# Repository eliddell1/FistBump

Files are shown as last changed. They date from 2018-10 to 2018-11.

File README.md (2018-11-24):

# FistBump
[](https://github.com/eliddell1/FistBump/releases)

[](https://github.com/eliddell1/Project-Blue-Fist)

_This Repo was a P.O.C. and is deprecated for a BLE peripheral Edition. STAY TUNED!_

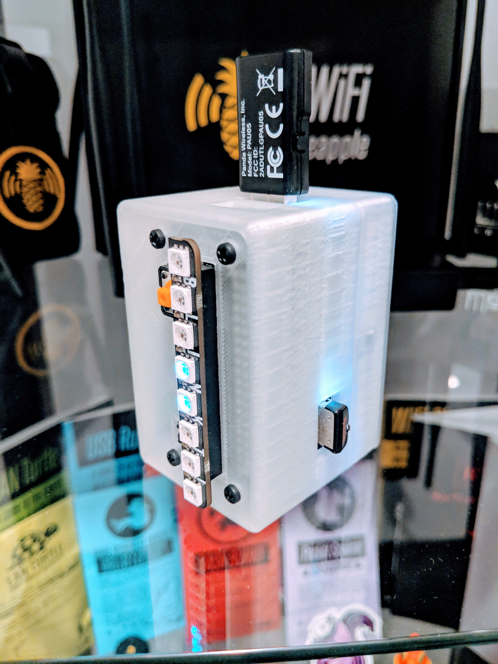
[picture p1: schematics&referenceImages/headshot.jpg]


## Introduction
When performing a typical deauth/wpa 4way handshake attack, one must get close enough to the target/clients for the deauth and capture to be effective. This can prove difficult in a typcial engagement, as one would draw suspicion setting up a laptop with a big wifi adapter sticking out and a bunch of terminal windows open.  It just screams hacker right? 

But what if you had a portable device that could launch such an attack with the click of a single button, while being small enough to be comfortably hidden in your hacker hoody pocket. A device with a low profile wifi adapter and removable storage where the handshakes are automatically stored so that you can easily transfer them to your hashcat rig when you get home. FistBump is a prototype of such a device. Did I mention it charges with a standard mini usb charger? Well it does.

__UPDATES__

As of __Version 2.0__ it will now also capture PMKID hashes as well. I migrated from aircrack to hcxdumptool.  I have left the old
fistbump.sh which utilizes the aircrack method in the repository incase for some reason someone wants that, but now the attack script is wpa_hashgrab.sh. _(It not only adds the capability to capture the PMKID hashes as well as 4 way handhsakes but its also much faster and a cleaner execution overall)_

As of __Version 2.1__ you can now target specific networks by saving a file named targets.txt to the removable USB drive with the BSSID(s) of your target(s) minus the colons. For instance, if your target BSSID is XX:XX:XX:XX:XX:XX, your targets.txt file will say XXXXXXXXXXXX. For multiple targets just put each BSSID on a new line.  HcxDumptool supports up to 64 specific targets. To revert back to a broad untargeted attack, simply remove the targets.txt file from your removable storage.

As of __version 2.2__ For every .2500 file created a .catalog file is also created of the same name.  This file is a catalog BSSIDs & ESSIDs of which handhsakes were captured. 

As of __version 2.3__ Removed all aircrack dependencies and killed wpa_supplicant instead of using `aircrack-ng check kill`

__Planned for Next Release__
* support potential capturing of plainmasterkeys, usernames and password

## Using FistBump

To power on FistBump, hold down the small button for about a second or until the red light on the bottom of the device goes off.  When the device is ready it will show either a __single green light__ or a __blue pulsing pattern__ on the strip of leds at the top of the device. Both indicate that the device is armed and ready to attack. The __single green light__ simply means there are currently no hashes stored on the device, while the __blue pulsing pattern__ indicates how many hash files are currently saved on the device. 

_Note: (pulse, pulse, pause, repeat) would mean 2 hash files are saved. Hash files can contain more than one hash and from more than one network. The hash files are saved to the external usb drive with the naming convention {date_time_Captured}.{hashcat mode}. For example, 4 way handshakes are cracked using `$ hashcat -m 2500... `, so a file containing 4 way handshakes would be named 201810290107.2500 while a PMKID hash file captured from the same attack would be 201810290107.16800, as the hashcat mode forcracking PMKID is 16800._  As of Version 2.1 if you specified a target (see updates section for v2.2), the captured hashes will be prepended with "targeted_" example: targted_201810290107.2500

### Starting an Attack 

To start an attack simply press the larger button.   

Before the actual attack begins, FistBump will make sure you have a USB thumb drive attached, where it will store the hashes it collects.  If no USB drive is present. it will light the strip up __solid red__ to indicate the missing drive and abort, sending you back to the ready state mentioned above.  Don't worry, you can simply insert your USB thumbdrive and try again. 

With a thumb drive present it will begin by putting your wifi adapter into the proper state, monitor mode, and kill any processes, like wpa_supplicant, that may interfere.  This stage will be indicated by a __purple scan pattern__. 

When you see a __random flashing rainbow pattern__ or __random flashing purple pattern__, the attack has begun! 
The Rainbow pattern indicates you are doing a broad attack while the purple pattern indicates that you have specified a target (see updates section for v2.1)

The attack leverages the latest WPA/WPA2 attack tool, [hcxdumptool](https://hashcat.net/forum/thread-7717.html) and is set to run for 40 seconds, which in my experience should be plenty of time to at least grab some handshakes.  If you wish to change this, you can edit the wpa_hashgrab.sh script found in scripts/FistBump/hashgrab.sh of this repository or in /home/pi/FistBump/ on the actual pi.

When the attack is complete you will see the strip of LEDs light up __solid purple__ if new hashes were collected during the attack, or __solid yellow__ if no new hashes were collected.

Now one might say, _"If I'm trying to be stealthy, whats with all these beautiful flashy LEDs?"_  Thats a valid point.  Again,
this is merely a proof of concept, but should you really have the need, the LED strip can be easily removed and replaced with out any altercations to the code. Of course then you just have to assume your attack went through and completed as you will have no indication.

### Powering Down

To power off FistBump, simply press the small power button again. The device will flash __solid yellow__ indicating a shutdown has begun.  Once all lights, external and internal are off, the device is off. The device will also begin a shutdown on its own when the battery gets dangerously low. This will also be indicated by the __solid yellow__ indicator and may come unexpectedly. Don't be alarmed as it is for the safety and integrety of the device img.

## Disclaimer

_This Device was developped as a proof of concept and for White Hat Purposes.  You should only use this device on your own or a consenting network and in a controlled enviroment, as sending the necessary deauth packets used in the contained scripts could be illegal in your given part of the world. I do not endorse or warrent breaking the law or invading the privacy of others. You alone are fully responsible for what you do with this info/device, and how you use it. I am not responsible for your actions. Please do not hack Wifi points that you are not allowed to!!!
Don't be a jerk!_

## What is here?
This repository contains all the Schematics, Reference Photos, Boot images, scripts, and even 3d printable encloser parts for creating a FistBump prototype device.

## Parts List

* [1 pi zero v1.3](https://www.raspberrypi.org/products/raspberry-pi-zero/)
_Do **NOT** use the wifi model as the chip doesn't support monitor/package injection and creates interferience on usb hub_

* [1 zero4u usb hub adapter](https://www.adafruit.com/product/3298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)

* [1 MakerSpot RPi Raspberry Pi Zero W Protoboard Breadboard](https://www.amazon.com/MakerSpot-Raspberry-Protoboard-Breadboard-Prototyping/dp/B01J9ILH7S)

* [2 10k resistors](https://www.amazon.com/Projects-25EP51410K0-10K-Resistors-Pack/dp/B01F06T56I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)

* [1 100k resistor](https://www.amazon.com/Projects-25EP514100K-100k-Resistors-Pack/dp/B0185FCGEY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)

* [3 1N4007 diodes]( https://www.amazon.com/100-Pieces-1N4007-Rectifier-Electronic/dp/B079KBFKK5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)

* 1 [small momentary button for power button](https://www.amazon.com/GZFY-6x6x4-5mm-Momentary-Tactile-Button/dp/B01N6GU7TA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)

* 1 [regular momentary button for Attack Trigger](https://www.amazon.com/Cylewet-12x12x7-3mm-Momentary-Tactile-Arduino/dp/B01NCQVGLC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)

* 1 [2.5 pi nylon screw set](https://www.adafruit.com/product/3299)

* 1 usb wifi adapter capable of monitor mode/ packet injection. I'd recommend the [Panda 300Mbps Wireless N USB Adapter](https://www.amazon.com/gp/product/B00EQT0YK2/ref=oh_aui_detailpage_o01_s00?ie=UTF8&psc=1) or even the [canaKit Wifi adapter](https://www.amazon.com/gp/product/B00GFAN498/ref=oh_aui_detailpage_o00_s01?ie=UTF8&psc=1) _both are capable of packet injection and fairly small YAY!_ or you could also use [this guy if you want and even smaller profile but its not as strong]( https://www.amazon.com/gp/product/B019XUDHFC/ref=oh_aui_detailpage_o00_s00?ie=UTF8&psc=1) 
For a more complete list of recommended devices [click here](https://null-byte.wonderhowto.com/how-to/buy-best-wireless-network-adapter-for-wi-fi-hacking-2018-0178550/)

* 1 [lo profile sandisk flash storage for saving handshakes in a removable manner](https://www.amazon.com/SanDisk-Cruzer-Low-Profile-Drive-SDCZ33-008G-B35/dp/B005FYNSUA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)

* 1 [16-32gb class 10 mirco sd card for pi boot image](https://www.amazon.com/s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)

* 1 [Pwerboost 1000c or 500c](https://www.adafruit.com/product/2465)

* 1 [3.7V 1200mAh PKCELL LP503562](https://www.amazon.com/s?k=3.7V+1200mAh+PKCELL+LP503562&ref=nb_sb_noss) _size matters we want a low profile as we will have a tight fit but feel free to alter this as you see fit espcially if you deisgn your own enclosuer etc_

* 1 [Pimoroni Blinkt!](https://shop.pimoroni.com/products/blinkt) _this will be your status indicator_

## Physical Assembly
For instructions on the physical assmebly follow the README file, [here](https://github.com/eliddell1/FistBump/blob/master/schematics%26referenceImages/README.md).  

I have also supplied freecad/stl files for the 3d printable encloser [here](https://github.com/eliddell1/FistBump/tree/master/EncloserFreeCad).

## Software Dependencies
This repository will supply a disk image built off [Raspbian STRETCH OS](https://github.com/eliddell1/FistBump/releases) in the releases section, that you can just write to a micro sd, pop into your piZero and be good to go! __username:pi password: fistbump__ That said, should you choose to build this yourself off of another OS or with modifications, be aware of the following dependencies.  The scripts for powering on and off the device as well as the attack button and actual attack have been suplied in the [scripts folder](https://github.com/eliddell1/FistBump/tree/master/scripts)

I chose to start the "arm_trigger" python script @reboot in crontab and the lipopi python script (for powering on and off the device) is set to start via /etc/rc.local

### version 1 dependencies

* aircrack-ng
`sudo apt install aircrack-ng`

* cowpatty
`wget http://www.willhackforsushi.com/code/cowpatty/4.6/cowpatty-4.6.tgz
tar zxfv cowpatty-4.6.tgz
cd cowpatty-4.6
make cowpatty
sudo cp cowpatty /usr/bin`

### version 2 dependencies 
* [hcxdumptool v4.2.0 or higher](https://github.com/ZerBea/hcxdumptool)

* [hcxtools v4.2.0 or higher](https://github.com/ZerBea/hcxtools)

### indicator depenencies
* blinkt! python library
`curl https://get.pimoroni.com/blinkt | bash`

## Credits
Credit where credit is due: 

* [ZerBera](https://github.com/ZerBea) for their development of hcxdumtool and hcxtools used in this prototype

* The powering on/off schematic and script were designed by [NeonHorizon](https://github.com/NeonHorizon/lipopi/blob/master/README.power_up_power_down.md)  

* Call out to 'atom' of the hashcat forums for this post: https://hashcat.net/forum/thread-7717.html

* special call out to icarus255 and the rest of the [Hak5 Community](https://forums.hak5.org) for being inspirational and all that.

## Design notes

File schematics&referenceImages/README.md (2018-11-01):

# Physical Build Instructions

The most difficult part of the phsyical assembly is the power on/off circut which is applied to the prototype board seen below.  In my setup the small black button is used for powering the device while the larger button is our trigger.

To fit in the 3d printable encloser included in this repo it is important to place these buttons in the exact positions seen on the images below.

__Top of proto board__

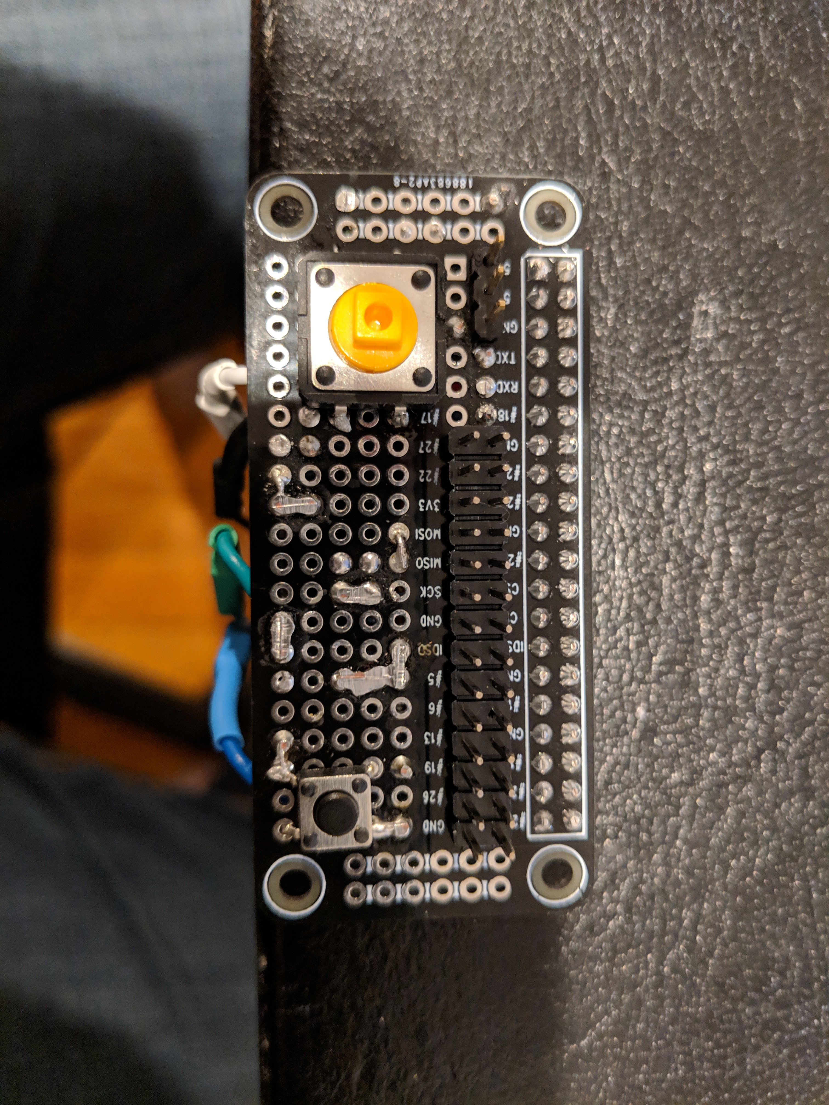
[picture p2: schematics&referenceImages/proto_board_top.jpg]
    

__Bottom of proto board__

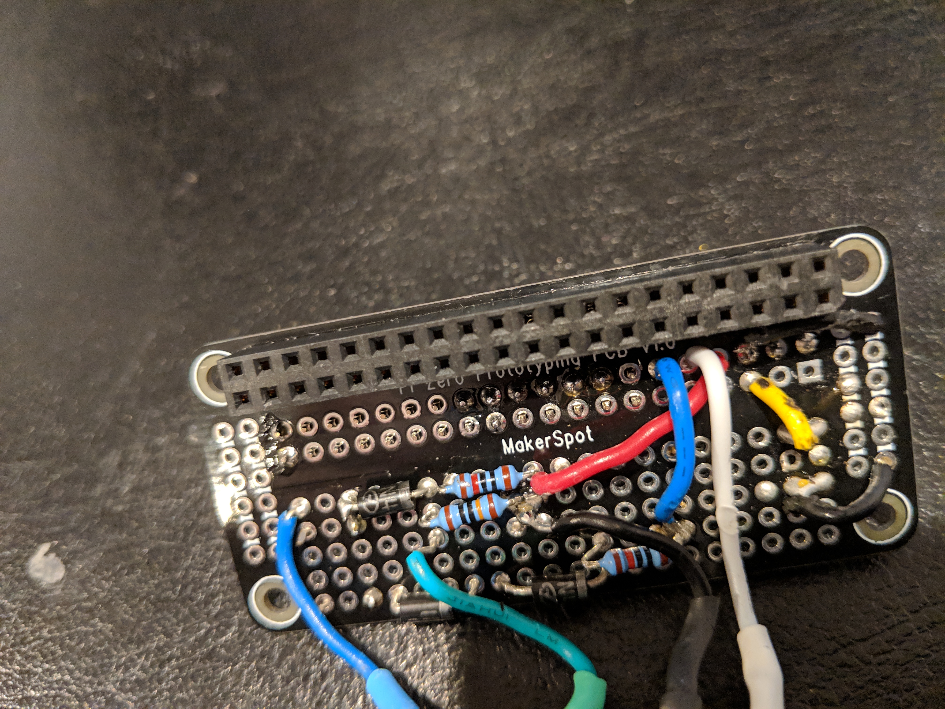
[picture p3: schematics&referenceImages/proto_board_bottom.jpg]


Obviously it is hard to tell much from those images so I will say this, it would probably behoove you to first solder the header pins, best seen in the top image, to the proto board.  We won't actually use all of them but they will be used for the blinkt chip and the extra pins will give support.  The trigger button ( larger yellow button) is simple, it needs to be wired to the ground (small black wire on right of the bottom image) and GPIO 3 (small yellow wire).

For the power cycle circut reference the bread board image below. Note that the wires coming off our proto board will attach to the powerboot and are color coded (light blue is battery, light green is env, black is ground and white will be low battery)

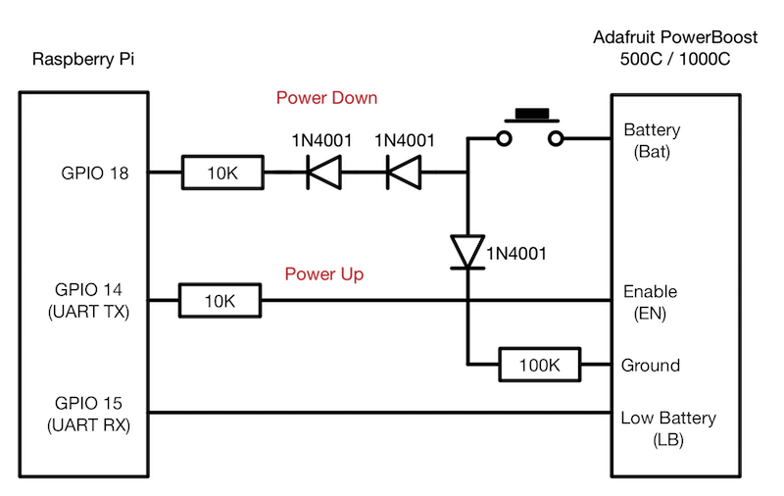
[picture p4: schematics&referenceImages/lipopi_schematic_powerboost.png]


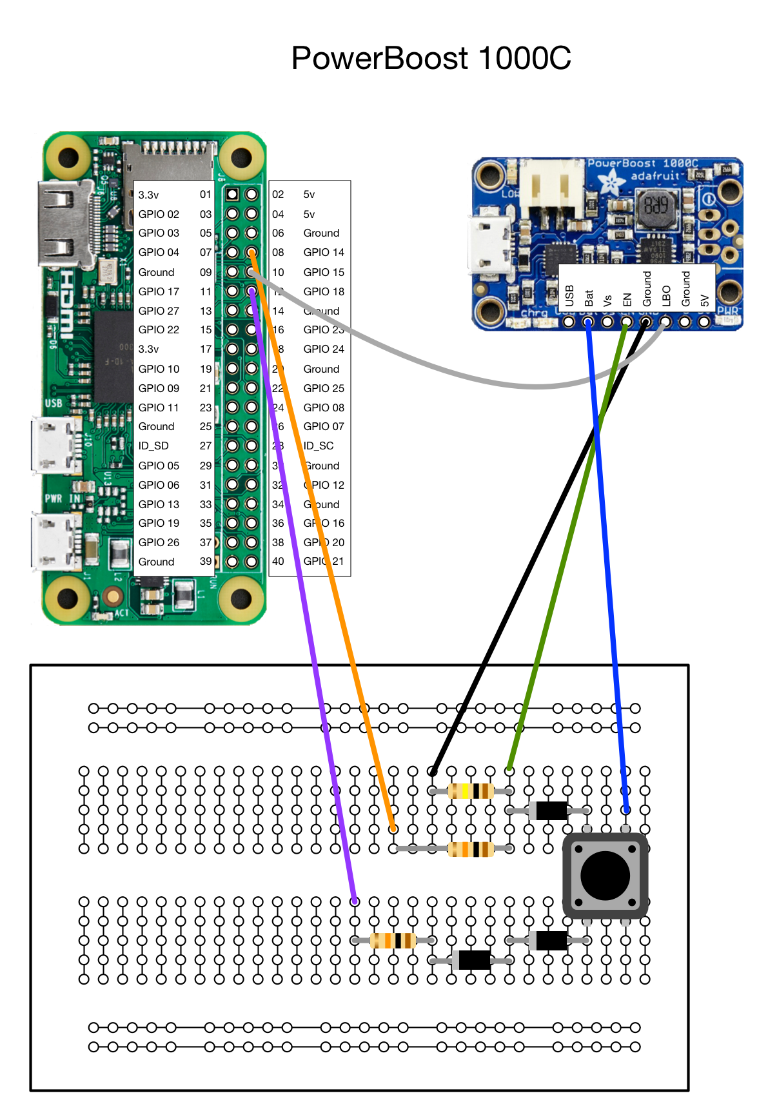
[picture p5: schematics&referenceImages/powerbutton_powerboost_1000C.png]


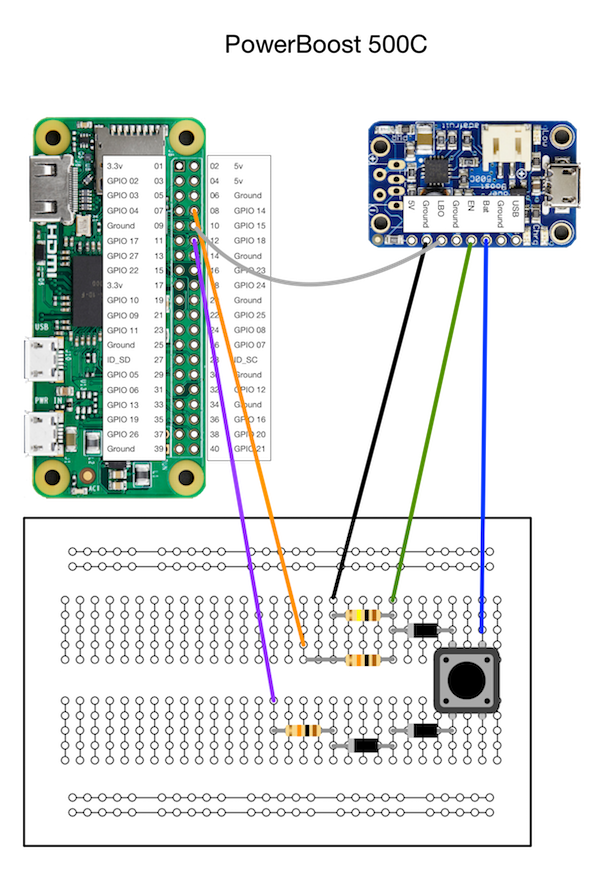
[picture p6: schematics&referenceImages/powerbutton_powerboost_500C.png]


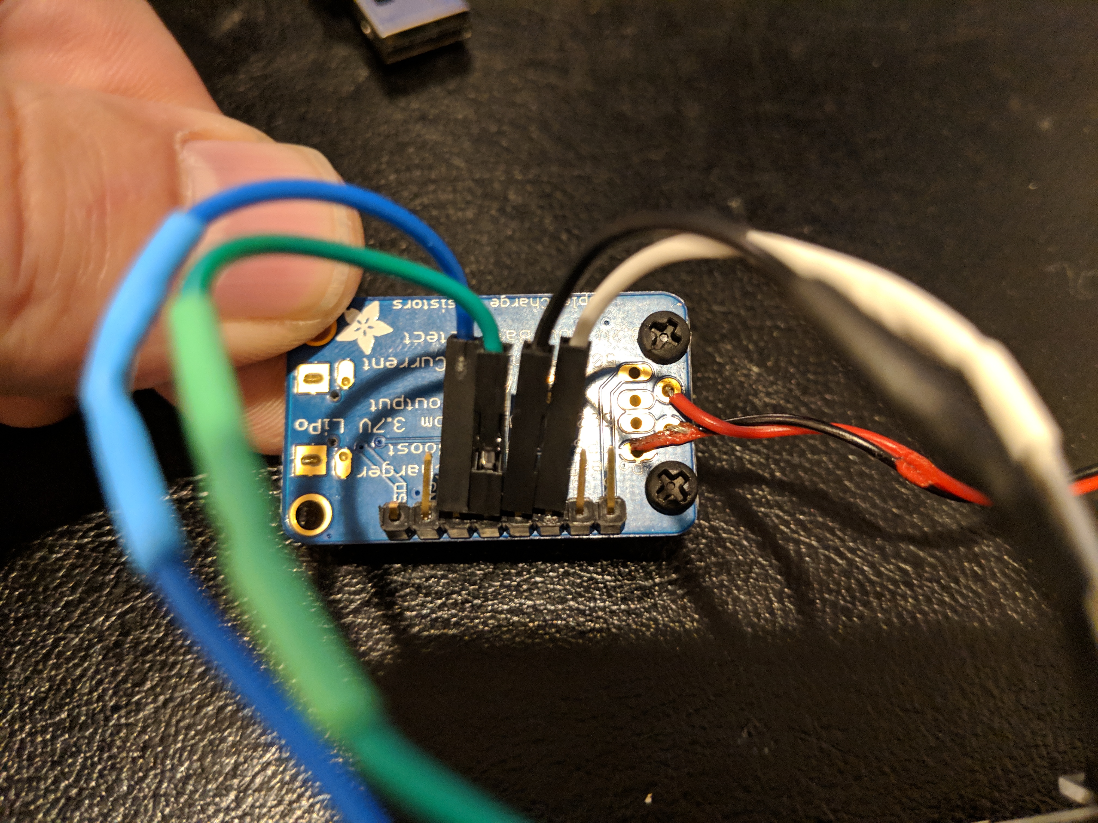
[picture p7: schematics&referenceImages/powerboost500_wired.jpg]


Note that in that last image im using the 500 power boost.. the order is different on the 1000

Once that proto board is all wired and soldered the rest is quite simple. And can be explained with the pics below.

We attach the pi zero to the zero4u usb hat like so:


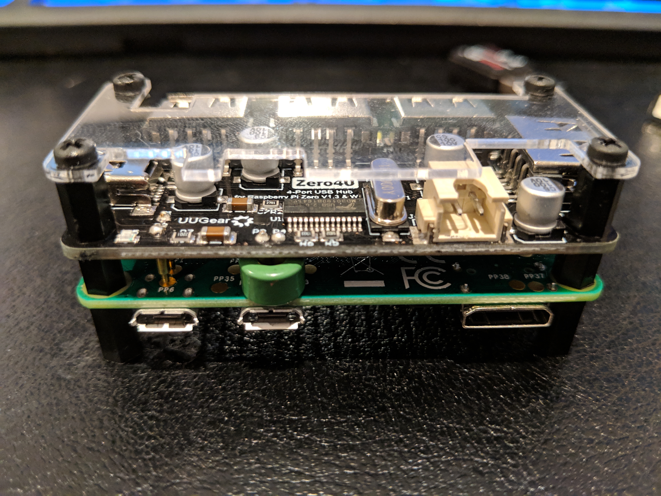
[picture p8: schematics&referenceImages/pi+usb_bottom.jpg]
 

In that bottom image you can see a piece of clear plastic that I basically salvaged from a PiBow zero case, probably not needed.

The proto board just plugs into the pi's headers and the blinkt! will plug into the proto boards headers.  make sure you attach the blinkt! with the rounded corners facing the closest edge of the pi.

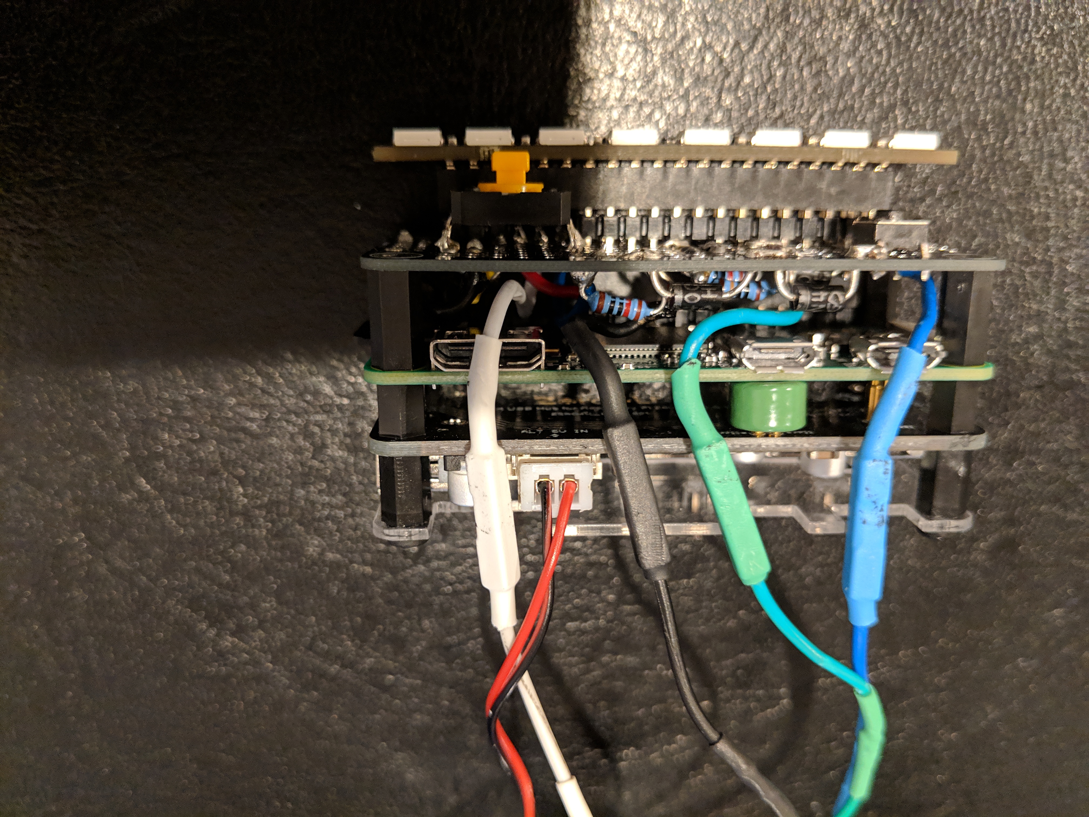
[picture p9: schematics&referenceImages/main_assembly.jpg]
 

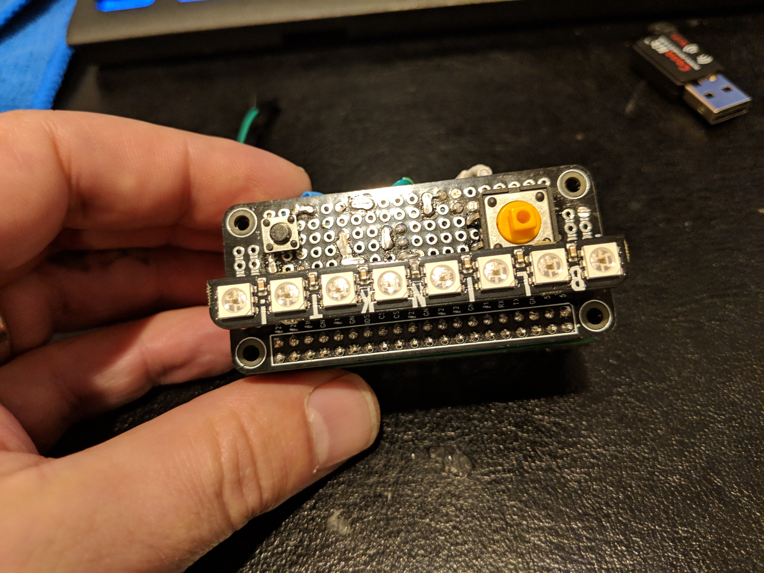
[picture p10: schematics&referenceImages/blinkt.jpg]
 

The lipo batter will plug directly to the power boost and the power out goes tothe zero4u hub which will supply power to the board.. 

Thats really it.  mostly plug n play!  just download the latest release image and write it to a micro sd card and pop it in.  You can thenjust plug in your wifi adapter and usb flash drive and power her up by holding the power button for about 1 second. :)

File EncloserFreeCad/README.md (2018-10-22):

# This Folder Contains FreeCad files for printing FistBump Encloser

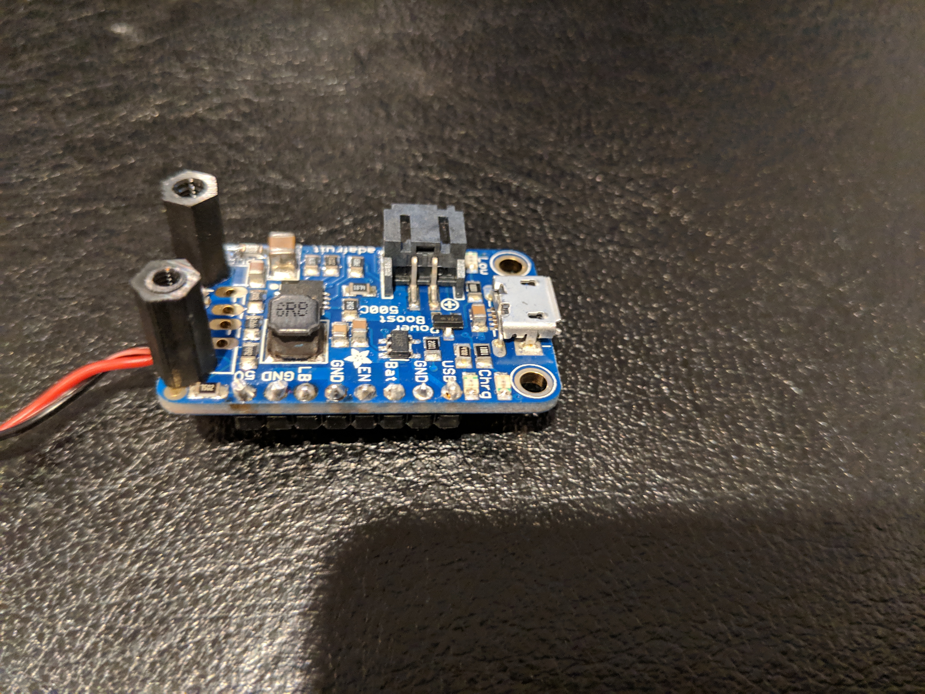
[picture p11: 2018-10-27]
schematics&referenceImages/powerboost_standoffs.jpg

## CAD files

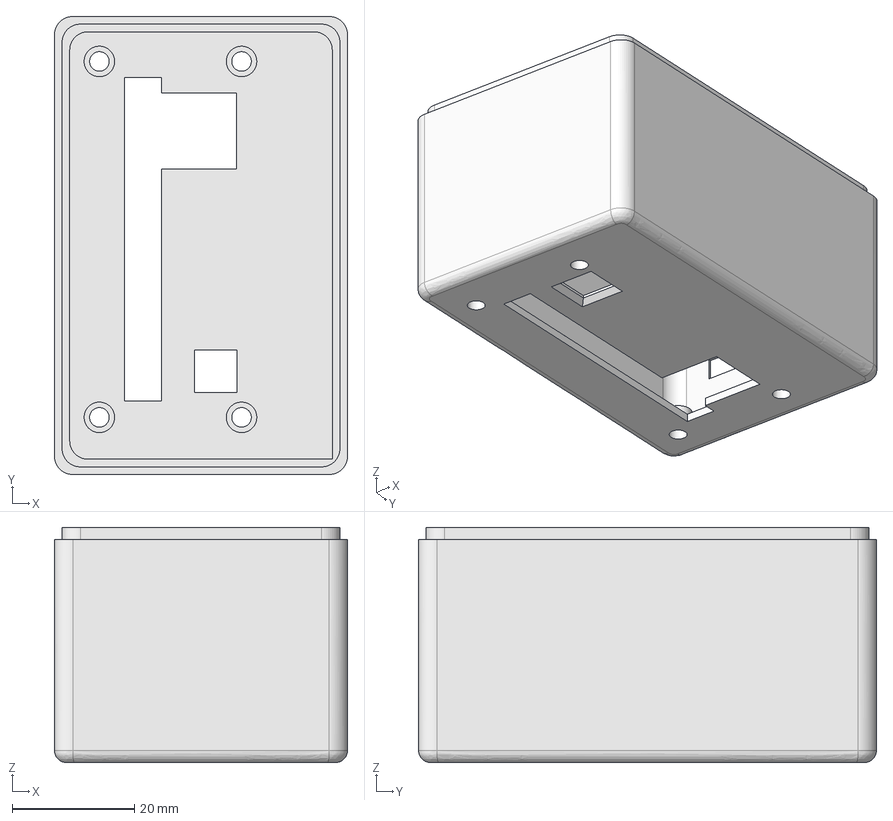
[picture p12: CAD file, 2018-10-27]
EncloserFreeCad/snap_case_bottom.fcstd
48.0 x 75.0 x 38.5 mm

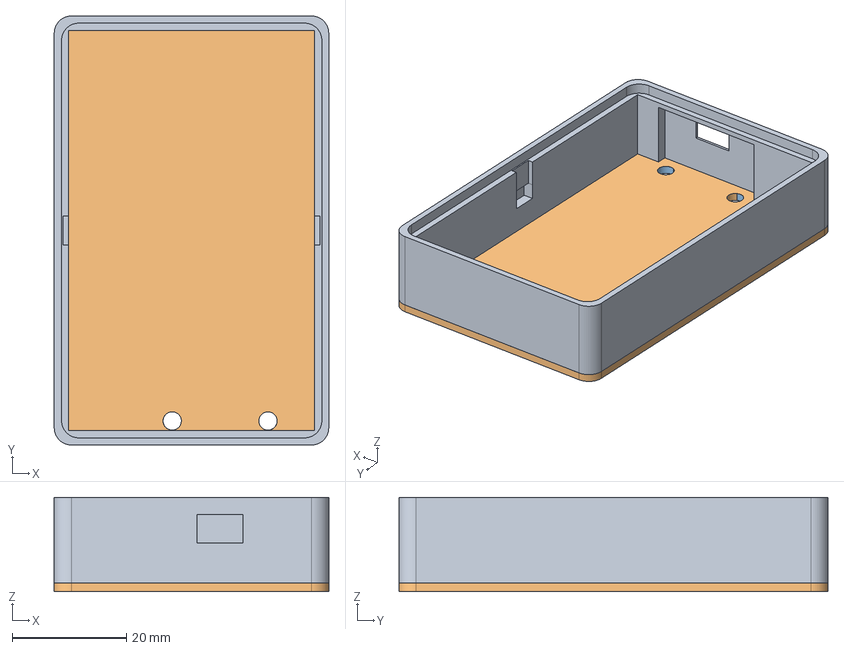
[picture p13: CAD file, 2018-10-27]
EncloserFreeCad/snap_case_top.fcstd
48.0 x 75.0 x 16.5 mm

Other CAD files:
EncloserFreeCad/snap_case_bottom.stl
EncloserFreeCad/snap_case_top.stl

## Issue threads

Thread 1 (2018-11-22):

Enhancement request - extra features

Mera-balou, 2018-11-22:
Hi Eric,

First of all, thank you for all this stuff.
Your project looks very nice and i will probably buy all items of the parts list in order to assembly my own FistBump for Christmas...

By the way, i wonder if theses extra features should be useful for a next release:
- it seems that you 've already add a whitelist target (through "targets.txt" file) but maybe a blacklist target (all SSID except these ones) could be helpful (eg. : a new file called "blacklist.txt")
- encrypt all the data of the removable USB drive. The cryptographic key could be loaded through a first  dedicated USB device at each startup. If the key is successfully loaded inside Raspbian memory (green light for example), the user can insert another USB storage to collect all the encrypted data. By this way, if the device is lost and checked by another people, data collected won't be revealed.
- collect not only hashes, but also client/AP MAC Address and geoloc if possible (if GPS antenna inserted), like wardriving app
- giving the opportunity to the user to deauth all clients of the SSID. Not for collecting hash but in order to denial the WIFI service.

What do you think about these ideas?

Of course, it will maybe take time to develop these kind of features and i want to thank you again to share this project. Next mission for me : find a 3d printer...

Mera

eliddell1, 2018-11-22:
Hey Mera,
Let me start with a thank you for your kind words.  Those are all pretty good ideas and i have been working on my own set of enhancements.  more on that later ;)   In the meantime, let me try and address each of your points.:

- This repo was really just for a proof of concept, and actually my newer version changes the way you target all together, but I'll give the blacklist ability a good thinking through.
- Encryption could be cool, but i actually never envisioned this leaving your person.  Its not meant to be a drop box by any means.  All though, could be cool to have the ability to remotely encrypt the entire device..now im hinting to my latest revision.
- originally i thought about collecting gps info as well, but wanted to keep the device itself as small as possible, but given that now the device is more of a peripheral we could leverage the geo location of your smart phone.
- A jammer ... it has been done and would complicate the legality of this device quite a bit..  easy enough for someone to mod if they wanted..

That said in case you have not figured out where i have taken this project in my private repository, here are a few more hints.

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

convince me to make that repo public :)

Mera-balou, 2018-11-30:
Holy shXXXX!

My bad, i had not figured out your new project "Project Blue Fist"... Pretty impressive.
My ideas about it, after your last response:
- encryption : maybe you can separate system partition from a data encrypted partition in Project Blue Fist removable storage. At startup, android apk asks user the password to decipher data part (with "remember me" option).
- wardriving: geolocate AP throught smartphone location is of course an excellent idea. Maybe your apk can launch a wardriving tool (like Kismet?) on the box if the user wants it. Now, it's maybe not so easy to correlate smartphone position with data retrieved by FistBump Device
- Wi-Fi deauthentication attack : is it really more complicate (legally point of view) than grab WPA handshakes and PMKID hashes?

Thanks for your work

Closed 2018-11-22.

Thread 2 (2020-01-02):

Wifite 2?

ProjectZeroDays, 2020-01-02:
Is there a way we can revamp a small arm device that uses a 4g Broadcom card and a separate internal adapter and run a light version of nethunter on it to make this work? There cactus 2 made a storm when they created a back pack with 22 pinnacle nanos to scan every channel independently with 42 antennas rear mounted in a special back pack.

https://youtu.be/3II3K44rQx4

I think you could run a light stripper down version or Kali for arm devices now using the new repository setup with just tools we need (tshark, pyrit, John, hashcrack, aircrack-ng suite, cowpatty, reaver, etc) and it’s dependencies using the built in hooks and build the exact metapackages needed to run it and have a light weight low power consumption device that could capture pmkid, and handshakes and use the built in api for onlinehashcrack.com (wlancap2wpasec -u https://api.onlinehashcrack.com -e projectzerodays@gmail.com handshake_ATT2V4y9Wg_14-ED-BB-CD-22-41_2019-12-30T17-49-26.cap handshake_MySpectrumWiFi362G_58-90-43-DD-A2-3C_2019-11-26T10-17-35.cap
handshake_RobertsWiFiNetwork_7C-D1-C3-CA-6C-94_2019-12-30T16-20-18.cap )

...using the Broadcom 3f/4g services to upload them to the cloud free where it can crack them using AWS servers using Highpowered NVDIA GPU processors to run the cracks against them. The only issue would be that wifite would need to reconfigured in python3 to allow hashcat handle the dump. If hcxdumptool does not handle the process itself it pollutes the handshake and will lead to a 99% failure rate. Now that I’m thinking of it, I can probably write this in a few days and make a distro avail online for pi users and we can run that on a 20k mil amp battery pack and carry it in a small backpack with 4 9db antennas to catch 2 and 5g and all you would have to do is use realVNC to remotely access the device in your back pack while walking using a cheap android tablet while walking using the untouched 4g while management the mostly automated wifite transactions while in monitor mode. If anyone is interested please let me know. The WHID pro elite uses a 3g/4g sim and create a wireless AP on airgapped systems and more to run cracks similar to this including
remotely inject keystrokes, bypass air-gapped systems, conduct mousejacking attacks, do acoustic surveillance, RF replay attacks and much more.

https://github.com/whid-injector/whid-31337

https://github.com/eliddell1/FistBump/issues/new

ProjectZeroDays, 2020-01-02:
Someone has done something similar but no 4g. https://gist.github.com/avin/9880dbd3b1dd6f718a298740fe26c134

ProjectZeroDays, 2020-01-02:
You may also want to read this thread: https://hashcat.net/forum/post-39288.html

ProjectZeroDays, 2020-01-02:
1)
wpa-sec moved to hashcat >= 4.0.1 and hcxtools >= 4.0.1
The python client (help_crack.py) is updated to version (0.9.0 / 10 Feb 2018)
BTW: you can help retrieving new PSKs, contributing GPU power (simple run the python client)
if you add the following line to help_crack.py (line 405):
os.system('cat help_crack.net >> wpasec_new.hccapx')
you will get a local copy of every network hashcat is working on.

2) somebody made a video of "Automated Wifi Attacks With HCXTOOLS"
https://www.youtube.com/watch?v=3-IhrlBpoQg

If we use this with the right supported WiFi/4g cards for pi, added a battery pack and antennas, you would be on the money:

So using that method, the pi, one of the following WiFi cards:

Right now this code supports this drivers in combination with a kernel >= 4.9:
USB ID 148f:7601 Ralink Technology, Corp. MT7601U Wireless Adapter
USB ID 148f:3070 Ralink Technology, Corp. RT2870/RT3070 Wireless Adapter
USB ID 148f:5370 Ralink Technology, Corp. RT5370 Wireless Adapter
USB ID 0bda:8187 Realtek Semiconductor Corp. RTL8187 Wireless Adapter
USB ID 0bda:8189 Realtek Semiconductor Corp. RTL8187B Wireless 802.11g 54Mbps Network Adapter
USB ID 0cf3:9271 Qualcomm Atheros Communications AR9271 802.11n
PCIe RTL8821AE 802.11ac PCIe Wireless Network Adapter

And the following 4G card:
S4 LTE-A (GT-I9506)

Then install hcxtools and download the python client:

help_crack.py (  )

Open it in Gedit and add the following line to help_crack.py (line 405):
os.system('cat help_crack.net >> wpasec_new.hccapx')
you will get a local copy of every network hashcat is working on and prevent the files from being polluted when hcxtools handles and dumps it.

Someone made a video of "Automated Wifi Attacks With HCXTOOLS"

https://www.youtube.com/watch?v=3-IhrlBpoQg

Wifite could be modified into a new various to support the option to let hcxtools handle the card during the needed operations and then hand it over back to wifite to run the remaining scans as well use hcxtools’ built in API to upload the files straight to onlinehashcrack.com using:

(wlancap2wpasec -u https://api.onlinehashcrack.com -e projectzerodays@gmail.com handshake_ATT2V4y9Wg_14-ED-BB-CD-22-41_2019-12-30T17-49-26.cap handshake_MySpectrumWiFi362G_58-90-43-DD-A2-3C_2019-11-26T10-17-35.cap
handshake_RobertsWiFiNetwork_7C-D1-C3-CA-6C-94_2019-12-30T16-20-18.cap )

The mobile version of wifite can be found here and further modified very quickly:

https://gist.github.com/avin/9880dbd3b1dd6f718a298740fe26c134

To offload the hashing using a free service with 20 million plus password combos using GPU driven cloud severs.

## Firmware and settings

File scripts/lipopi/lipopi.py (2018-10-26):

#!/usr/bin/env python

# lipopi.py

# Example python script that uses the LiPoPi circuitry to handle the safe shutdown of
# a Raspberry Pi in response to user request or low battery

# See the README file for details on how to set this up with systemd

# this script is called by /etc/systemd/system/lipopi.service

# This version uses the GPIO event trigger machinery

# 2016 - Robert Jones - Freely distributed under the MIT license

# based on Daniel Bull's LiPoPi project - https://github.com/NeonHorizon/lipopi

import os
import RPi.GPIO as GPIO
import time

# Configure the GPIO pins

def lipopi_setup():
    global lipopi

    GPIO.setwarnings(False)
    GPIO.setmode(GPIO.BCM)

    # setup the pin to check the shutdown switch - use the internal pull down resistor
    GPIO.setup(lipopi['shutdown_pin'], GPIO.IN, pull_up_down=GPIO.PUD_DOWN)

    # setup the low battery check pin
    GPIO.setup(lipopi['low_battery_pin'], GPIO.IN)

    # create a trigger for the shutdown switch and low battery pins

    GPIO.add_event_detect(lipopi['shutdown_pin'], GPIO.RISING, callback=lipopi_user_shutdown, bouncetime=300)

    GPIO.add_event_detect(lipopi['low_battery_pin'], GPIO.FALLING, callback=lipopi_low_battery_shutdown, bouncetime=300)

    # open log file in append mode
    lipopi['logfile_pointer'] = open(lipopi['logfile'], 'a+')


# Detect when the switch is pressed - wait shutdown_wait seconds - then shutdown

def lipopi_user_shutdown(channel):
    global lipopi

    os.system("sudo python /home/pi/FistBump/rgb.py 255 150 0")
    cmd = "sudo wall 'System shutting down in %d seconds'" % lipopi['shutdown_wait']
    os.system(cmd)

    time.sleep(lipopi['shutdown_wait'])

    msg = time.strftime("User Request - Shutting down at %a, %d %b %Y %H:%M:%S +0000\n", time.gmtime())
    lipopi['logfile_pointer'].write(msg)
    lipopi['logfile_pointer'].close()
    GPIO.cleanup()
    os.system("sudo shutdown now")


# Respond to a low battery signal from the PowerBoost and shutdown
# Pin goes low on low battery

def lipopi_low_battery_shutdown(channel):
    global lipopi
    os.system("sudo python /home/pi/FistBump/rgb.py 255 150 0")
    cmd = "sudo wall 'System shutting down in %d seconds'" % lipopi['shutdown_wait']
    os.system(cmd)

    time.sleep(lipopi['shutdown_wait'])

    msg = time.strftime("Low Battery - Shutting down at %a, %d %b %Y %H:%M:%S +0000\n", time.gmtime())
    lipopi['logfile_pointer'].write(msg)
    lipopi['logfile_pointer'].close()
    GPIO.cleanup()
    os.system("sudo shutdown now")

# Close the log file, reset the GPIO pins
def lipopi_cleanup():
    global lipopi
    lipopi['logfile_pointer'].close()
    GPIO.cleanup()



# Main --------------------------------------------


# Setup LiPoPi global variable array

lipopi = {}

# Specify which GPIO pins to use
lipopi['low_battery_pin'] = 15

lipopi['shutdown_pin']    = 18

lipopi['logfile'] = '/home/pi/lipopi.log'  # FULL path to the log file
# or do this relative to the location of this script?

lipopi['shutdown_wait'] = 2  # seconds - how long to wait before actual shutdown - can be 0 if you want

# setup the GPIO pins and event triggers

lipopi_setup()

# Although the shutdown is triggered by an interrupt, we still need a loop
# to keep the script from exiting - just do a very long sleep

while True:
    time.sleep(6000)

# clean up if the script exits without machine shutdown

lipopi_cleanup()

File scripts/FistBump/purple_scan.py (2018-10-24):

#!/usr/bin/env python

import time

import blinkt

blinkt.set_clear_on_exit()

REDS = [0, 0, 0, 0, 0, 16, 64, 255, 64, 16, 0, 0, 0, 0, 0, 0]

start_time = time.time()

while True:
    # Sine wave, spends a little longer at min/max
    # delta = (time.time() - start_time) * 8
    # offset = int(round(((math.sin(delta) + 1) / 2) * (blinkt.NUM_PIXELS - 1)))

    # Triangle wave, a snappy ping-pong effect
    delta = (time.time() - start_time) * 16
    offset = int(abs((delta % len(REDS)) - blinkt.NUM_PIXELS))

    for i in range(blinkt.NUM_PIXELS):
        blinkt.set_pixel(i, REDS[offset + i], 0, REDS[offset + i], .1)

    blinkt.show()

time.sleep(0.1)

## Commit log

2018-10-24 Add files via upload
    update working with LED indicators
2018-10-25 added led status indicator and fixed some bugs
    [arm_trigger.py, purple_scan.py, random_colors.py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]
2018-10-27 clean up images, touch up attach
    [snap_case_bottom.fcstd, snap_case_bottom.stl, snap_case_top.fcstd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]
2018-10-30 Revert "migration to hcxdump for efficency and add pmkid attack"
    This reverts commit 443ba859589164fb6205095129a7f942b574520c.
    [arm_trigger.py]
2018-10-30 fixed bug when no usb not returning to arm state, added support for targeting
    [arm_trigger.py]
2018-11-01 add schematic for power switch
    breadboard images doen't clearly show which resistors go where
2018-11-02 Update arm_trigger.py
    minor fix
    [arm_trigger.py]
